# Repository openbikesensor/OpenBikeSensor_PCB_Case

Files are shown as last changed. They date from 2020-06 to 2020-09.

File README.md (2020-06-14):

# OpenBikeSensor_pcb_case

## empfohlene Layerhöhen für easyPrint-Dateien
Alle Bereiche werden mit 0.1mm empfohlen
- Maincase: 4.8-5.6mm und 5.8-6.6mm
- Batterie-Sensor-Holder: 6.8-7.6mm
- OBS-D-001-V1_easyPrint: 3.6-4.3mm

## Was ist easyPrint?

Das größte Problem bei der FDM Methode des 3D-Drucks ist, dass es unmöglich ist in die Luft zu drucken. Habe ich eine Öffnung und möchte diese mit einem kleineren Loch weiter drucken bleiben mir zwei Möglichkeit. 
1. ich benutze Support. Dann wird unter den Kreis für das neue kleinere Loch eine Stützstruktur gedruckt die diesen Kreis auffängt. Nachteil dabei ist es wird mehr Material benutzt und ich muss diese Stützstruktur später entfernen.
2. ich benutze Bridging. Es wird also eine Brücke gespannt. Hat man seinen Drucker gut abgestimmt kann man gerade Abschnitt überbrücken ohne eine Stützstruktur darunter zu benötigen.

Den Fall 2 mache ich mir hier zu nutze. Da mein Loch nicht geradlinig sondern rund ist müssen ein paar Stufen eingefügt werden, die mit Brindging gedruckt werden können und ein paar Schichten später dann den eigentlichen Kreis stützen.
Zu sehen ist dieser Effekt in den nachfolgenden Bildern.

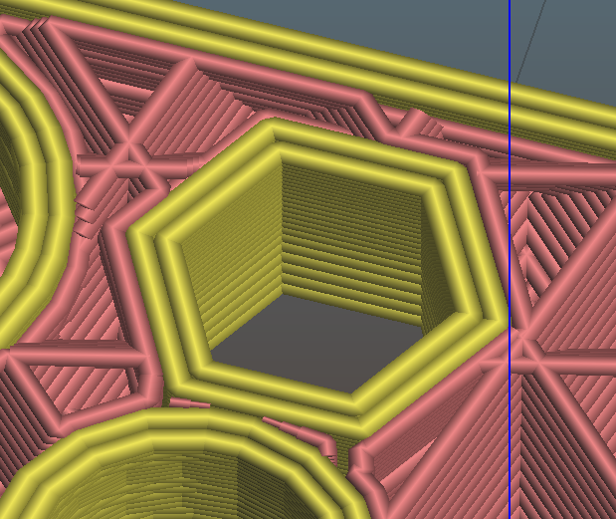
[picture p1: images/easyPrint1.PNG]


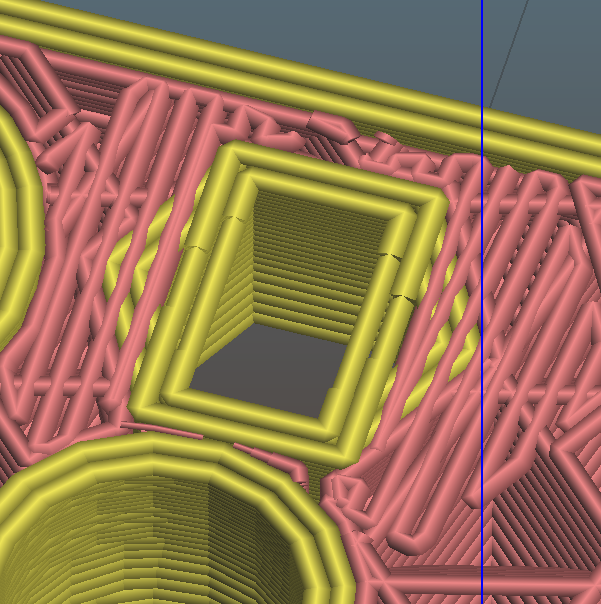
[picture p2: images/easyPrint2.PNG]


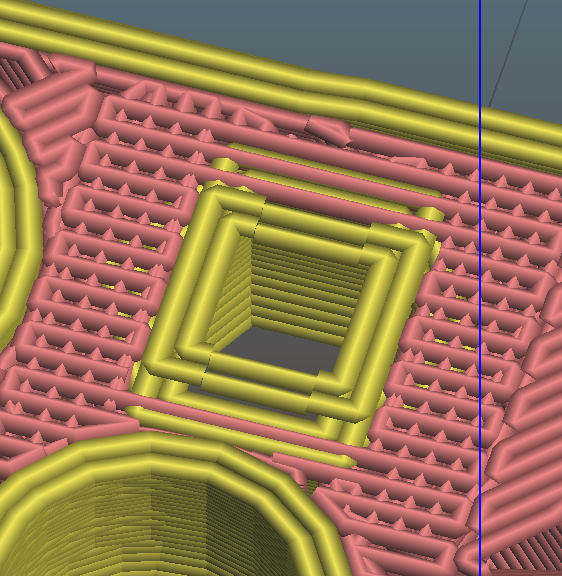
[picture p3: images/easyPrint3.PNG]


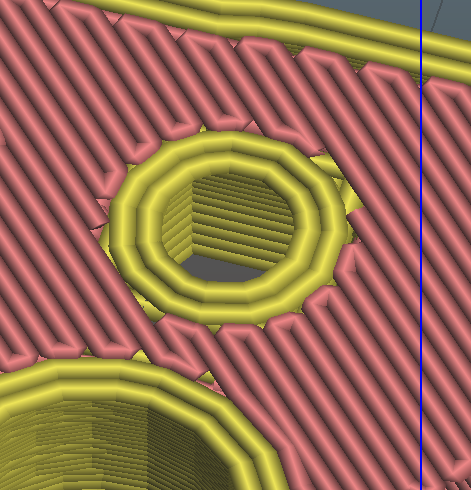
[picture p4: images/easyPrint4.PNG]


Das einzige, das jetzt zu tun bleibt, ist auf den entsprechenden höhen die Layerhöhe auf etwas unter die Höhe dieser Stufen zu reduzieren, damit diese von Slicer nicht wegapproximiert werden. Außerdem gilt, um so größer der zu stützende Kreis wird, um so mehr dieser Stufen benötige ich. Der Kreis muss also mit umso mehr Ecken angenähert werden. Für ein Loch mit 3-5mm reicht allerdings eine Näherung mit 4 Ecken vollkommen aus.

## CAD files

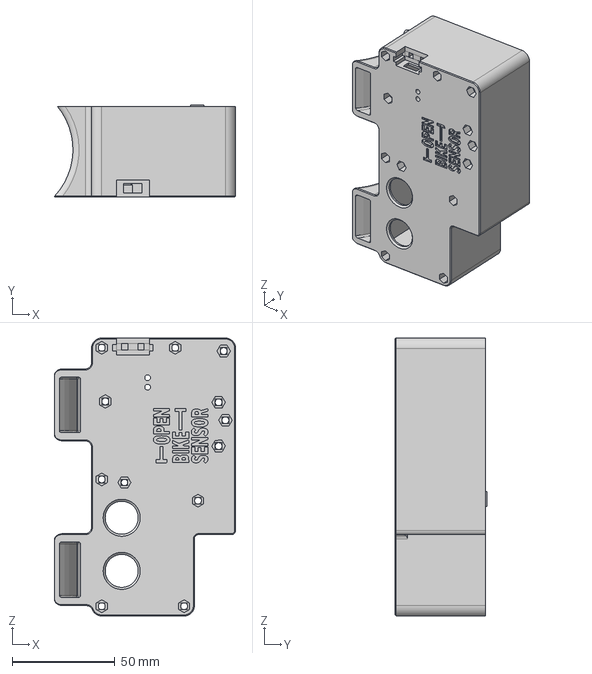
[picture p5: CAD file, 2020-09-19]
Case_Mainpart_easyPrint.step
88.0 x 44.7 x 135.0 mm

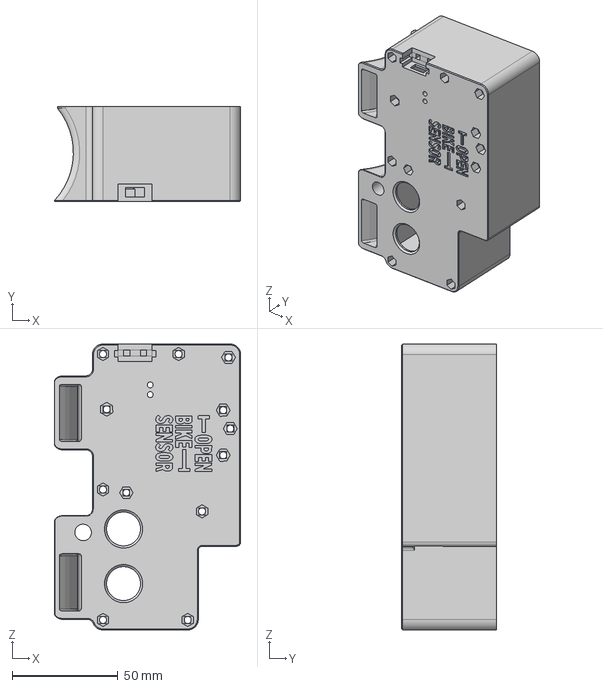
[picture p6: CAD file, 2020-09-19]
upside_down_logo/Case_Mainpart_CableLock_easyPrint.step
88.0 x 44.8 x 135.0 mm

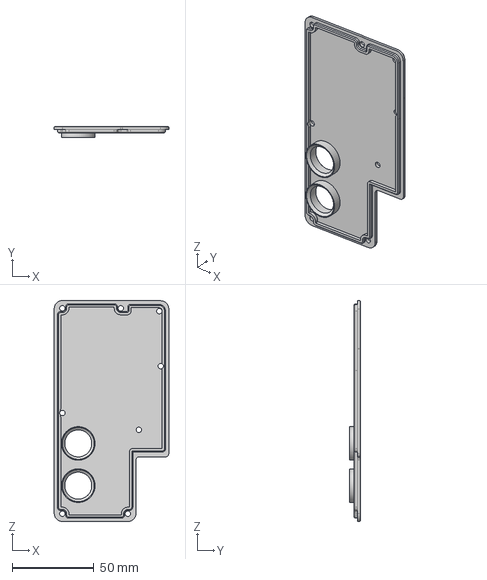
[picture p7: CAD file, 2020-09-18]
upside_down_logo/Case_Cover.step
70.0 x 7.00 x 135.0 mm

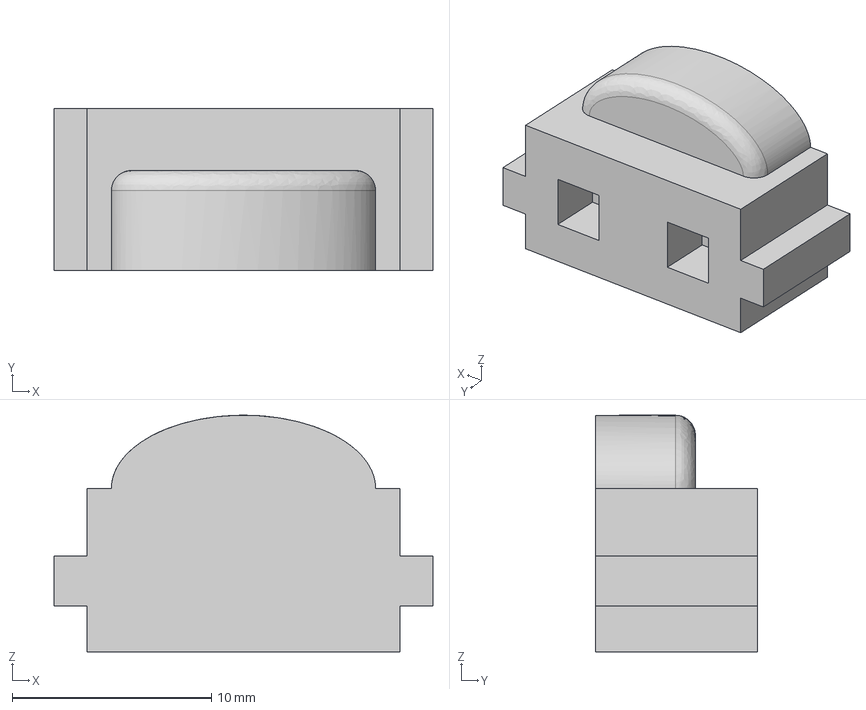
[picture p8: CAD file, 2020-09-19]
Case_USB_Cover.step
19.0 x 8.10 x 11.9 mm

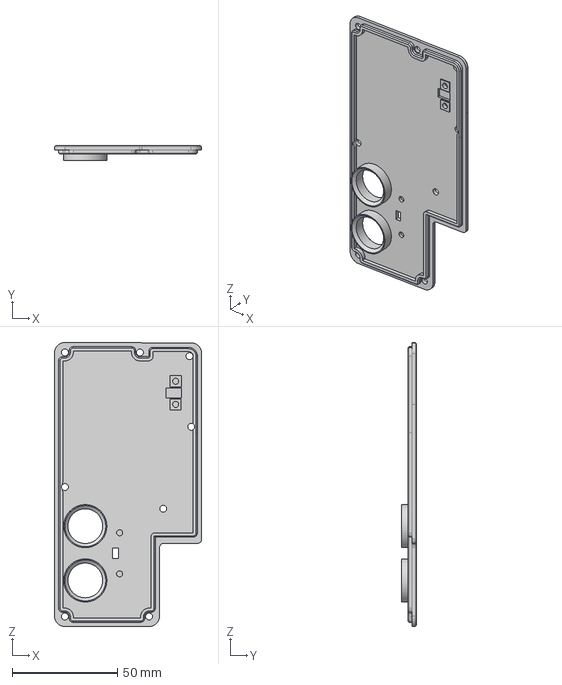
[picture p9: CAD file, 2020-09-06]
Case_Cover_with_BMP280_VL53L1X_updown.step
70.0 x 7.00 x 135.0 mm

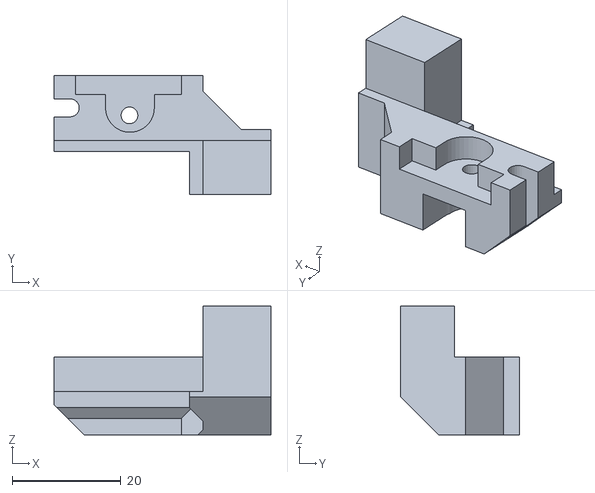
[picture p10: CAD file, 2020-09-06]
Case_Batterie_Sensor_holder_easyPrint.stl
40.0 x 22.0 x 23.7

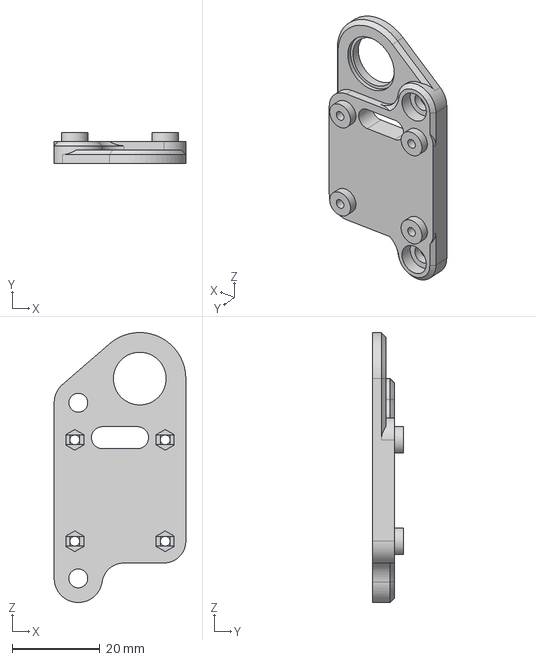
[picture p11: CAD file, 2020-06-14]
OBS-D-001-V1_easyPrint.step
30.0 x 7.00 x 61.5 mm

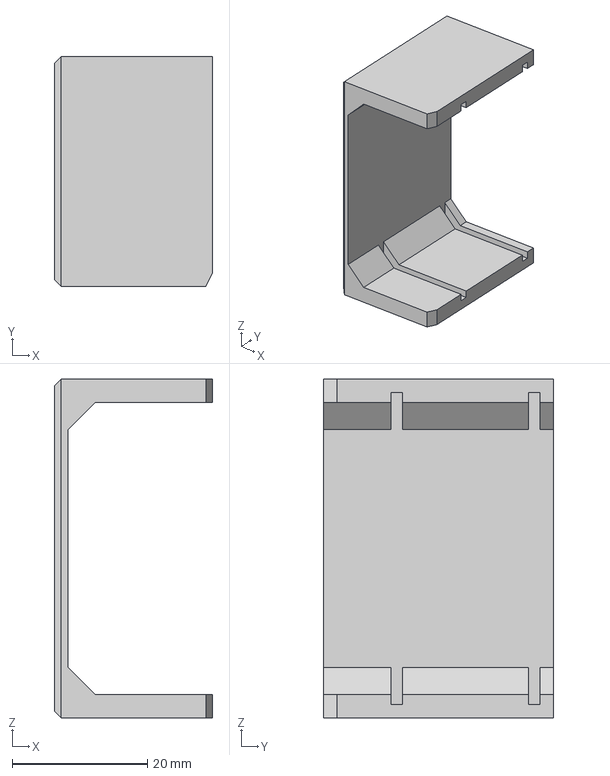
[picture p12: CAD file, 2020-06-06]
OBS-C-004-V1.step
23.4 x 34.0 x 50.2 mm

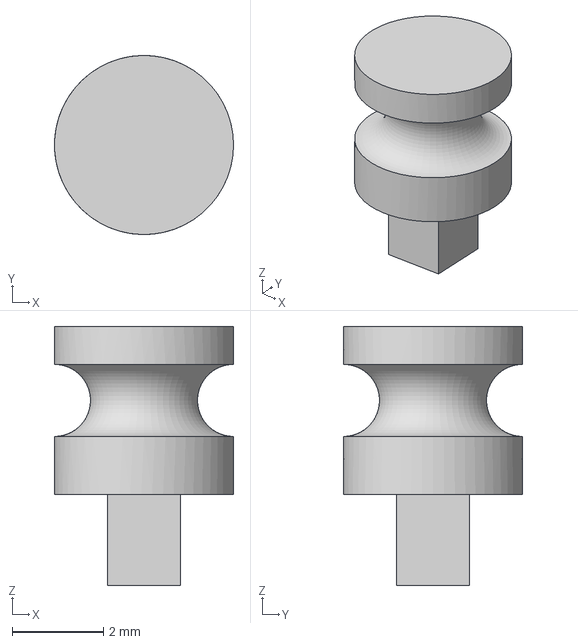
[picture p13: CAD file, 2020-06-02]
Case_USB_Cover_Sauele.step
3.93 x 3.93 x 5.69 mm

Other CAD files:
Case_Mainpart.step
Case_Mainpart_CableLock_easyPrint.step
upside_down_logo/Case_Cover_with_BMP280_VL53L1X.step
upside_down_logo/Case_Cover_with_BMP280.step
Case_Cover_with_BMP280.step
Case_Cover_with_BMP280_VL53L1X.step
Case_Cover.step
Case_Batterie_Sensor_holder.step
Case_Batterie_Sensor_holder.stl
Case_Cover.stl
Case_Cover_with_BMP280.stl
Case_Cover_with_BMP280_VL53L1X.stl
Case_Cover_with_BMP280_VL53L1X_updown.stl
Case_Mainpart.stl
Case_Mainpart_CableLock_easyPrint.stl
Case_Mainpart_easyPrint.stl
Case_USB_Cover.stl
Case_USB_Cover_Sauele.stl
OBS-C-004-V1.stl
OBS-D-001-V1_easyPrint.stl
upside_down_logo/Case_Cover.stl
upside_down_logo/Case_Cover_with_BMP280.stl
upside_down_logo/Case_Cover_with_BMP280_VL53L1X.stl
upside_down_logo/Case_Mainpart_CableLock_easyPrint.stl

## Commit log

2020-06-02 Inital Version
    [Case_Cover.step, Case_Cover.stl, Case_Mainpart.step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]
2020-06-04 cutout for MT3608 updated
    coutouts for magnets usb cover added
    [Case_Mainpart.step, Case_Mainpart.stl, Case_USB_Cover.step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]
2020-06-04 Porject file updated Mt3608 cutout magnet cutouts
2020-06-05 Batterie/Sensor holder added and main part adjusted
    [Case_Batterie_Sensor_holder.step, Case_Batterie_Sensor_holder.stl, Case_Mainpart.step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]
2020-06-06 Mainpart was wrong uploaded --> fixed
    [Case_Mainpart.stl]
2020-06-06 Sensor frame from original project added
    [OBS-C-004-V1.step, OBS-C-004-V1.stl]
2020-06-07 aasyPrint for Sensor holder and Mainpart added
    [Case_Batterie_Sensor_holder_easyPrint.stl, Case_Mainpart_easyPrint.stl]
2020-06-14 updated Easy Print heights
    [Case_Batterie_Sensor_holder_easyPrint.stl, Case_Mainpart_easyPrint.stl]
2020-06-14 Added images
    Added easyPrint Version for Display Part
    [OBS-D-001-V1_easyPrint.step, OBS-D-001-V1_easyPrint.stl]
2020-06-15 Added a version with a Lock for a Cable Lock
    [Case_Mainpart_CableLock_easyPrint.step, Case_Mainpart_CableLock_easyPrint.stl, Case_Mainpart_easyPrint.step]
2020-07-27 fixed rotated ESP32
    [Case_Cover.step, Case_Cover.stl, Case_Mainpart.step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]
2020-07-27 Project file updated and switched from f3d to f3z
2020-08-01 made a little cutout for the gps headers
    [Case_Mainpart.step, Case_Mainpart.stl, Case_Mainpart_CableLock_easyPrint.step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]
2020-08-02 fixed mid air printed part in center of part
    [Case_Mainpart.step, Case_Mainpart.stl, Case_Mainpart_CableLock_easyPrint.step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]
2020-08-16 improved case for <00.02.04 (switch) added case for >00.02.05
    [Case_Cover.step, Case_Cover.stl, Case_Mainpart.step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]
2020-09-06 updated for 00.02.05 tested with board some slight problems with fit of magnets
    [Case_Batterie_Sensor_holder.stl, Case_Batterie_Sensor_holder_easyPrint.stl, Case_Cover.step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]
2020-09-15 Updated Case and Lid with BMP280
    [Case_Cover_with_BMP280.stl, Case_Mainpart.stl, Case_Mainpart_CableLock_easyPrint.stl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]
2020-09-15 updated Lid with Logo
    [Case_Cover.stl]
2020-09-18 Updated all Case versions with logo -added versions with logo upside down -updated USB cover to an other shape Case_USB_Cover_B.stl/Case_USB_Cover_B.step
    added .f3d file for project again
    [Case_Cover.step, Case_Cover.stl, Case_Cover_with_BMP280.step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]
2020-09-18 Renamed USB case cover; old one was obsolete
    [Case_USB_Cover.step, Case_USB_Cover.stl, Case_USB_Cover_B.step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]
2020-09-19 extended all magnet inserts to 3.3mm
    [Case_Mainpart.step, Case_Mainpart.stl, Case_Mainpart_CableLock_easyPrint.step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]
